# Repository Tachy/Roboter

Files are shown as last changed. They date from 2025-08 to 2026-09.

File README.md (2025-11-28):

Ein rein solarbetriebener Roboter, der auf Pflasterflächen aus den Ritzen wachsendes Unkraut mit KI-Bildauswertung erkennt, anfährt und gezielt mit einer rotierenden Drahtbürste wegbürstet ;)

Mechanik: vorwiegend goBilda-Teile und Pololu-Motoren

Solarpanel: 12 V 50 Wp

Batterie: LiFePo 12 V 6 Ah

Solar-Laderegler: Victron MPPT 75/10

Gehäuseteile: 3D Druck 

Konstruktion Mechanik: Autodesk Fusion 360 private

Entwurf Elektronik: Fritzing

Energiemanagement: Arduino Pro Mini 5V

Motorsteuerung: Arduino MEGA

Bilderkennung mit KI: Raspberry Pi 4B mit RaspBerry HQ Kamera

Besonderheit: wurde zur Einarbeitung in KI vollständig "vibe" coded, über den github-Copilot mit Agent / Auto

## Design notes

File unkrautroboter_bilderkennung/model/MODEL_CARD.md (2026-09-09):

# Model Card – Unkrautroboter Detektionsmodell

Provenienz-Datei für das auf dem Pi laufende YOLO-Modell. Das eigentliche Gewicht
(`best.pt`, `best_ncnn_model/`, `best.onnx`) ist **nicht** in Git – es lebt auf der
Trainingsmaschine `.17` unter `~/lightly/models/registry/<ts>/` und kommt per
`bin/deploy-model.sh` auf den Pi. Diese Datei wird vom Trainer (`yolo-training/trainer/
train_now.py`) geschrieben und bei einer Promotion vom Menschen committet.

## Aktuell ausgeliefert

| Feld | Wert |
|---|---|
| Registry-ID | `20260909213903` (`.17:~/lightly/models/registry/20260909213903/`) |
| Dateien | `best.pt`, `best_ncnn_model/`, `best.onnx` |
| best.pt sha256 | `2101b0efd090f16339e3cd45afe058cd4d989780ad05c420fc0ecb69ca061c5d` |
| Architektur | **YOLO26s** |
| Laufzeit auf dem Pi | NCNN FP16 (`YOLO_RUNTIME="ncnn"`) |
| Klassen | `0: unkraut`, `1: moos` |
| Trainings-/Inferenz-imgsz | 1280 |
| Basisgewichte | `yolo26s.pt` |
| ultralytics | 8.4.146 |
| Holdout-mAP50-95 | 0.955 — **auf Fake-Bildern, nicht aussagekräftig** |
| Gate | bypassed (`--no-gate`, Bootstrap) |
| Datum | 2026-09-09 |
| Quelle | `train_now.py --base yolo26s.pt` auf ~44 **synthetischen** Bildern |

> ⚠️ **Bootstrap-Modell.** Nur der Architektur-/Pipeline-Umstieg v8m → YOLO26s NCNN@1280.
> Auf Fake-Bildern trainiert, erkennt kein echtes Unkraut. Wird beim ersten Echtdaten-Lauf
> über die Modell-OTA ersetzt (Dashboard-Button, Checkbox „Basis: YOLO26s" dann NICHT mehr
> nötig). v8m-Fallback liegt auf dem Pi unter `model/best.pt.v8m`.

## Historie

- 2026-09-09 – **YOLO26s**, imgsz 1280, NCNN FP16, Klassen `unkraut`/`moos`. Bootstrap
  auf synthetischen Bildern, um Trainings-Pipeline + Pi-Laufzeit auf YOLO26 umzustellen.
  Registry `20260909213903` auf `.17`, manuell in `/home/admin/model/` gestaged +
  `config.py` auf `ncnn`/1280 geflippt.
- 2025-08-13 – YOLOv8m, imgsz 640, sha256 `c2c24c64…f61a244`, Basis `yolov8m.pt`. Erster
  in Git eingecheckter Stand; ab Plan *adaptive-orbiting-fountain* aus Git entfernt
  (`git rm --cached`) und auf `.17` als „home of record" abgelegt. Liegt auf dem Pi noch
  als `model/best.pt.v8m` (Notfall-Rückfall).

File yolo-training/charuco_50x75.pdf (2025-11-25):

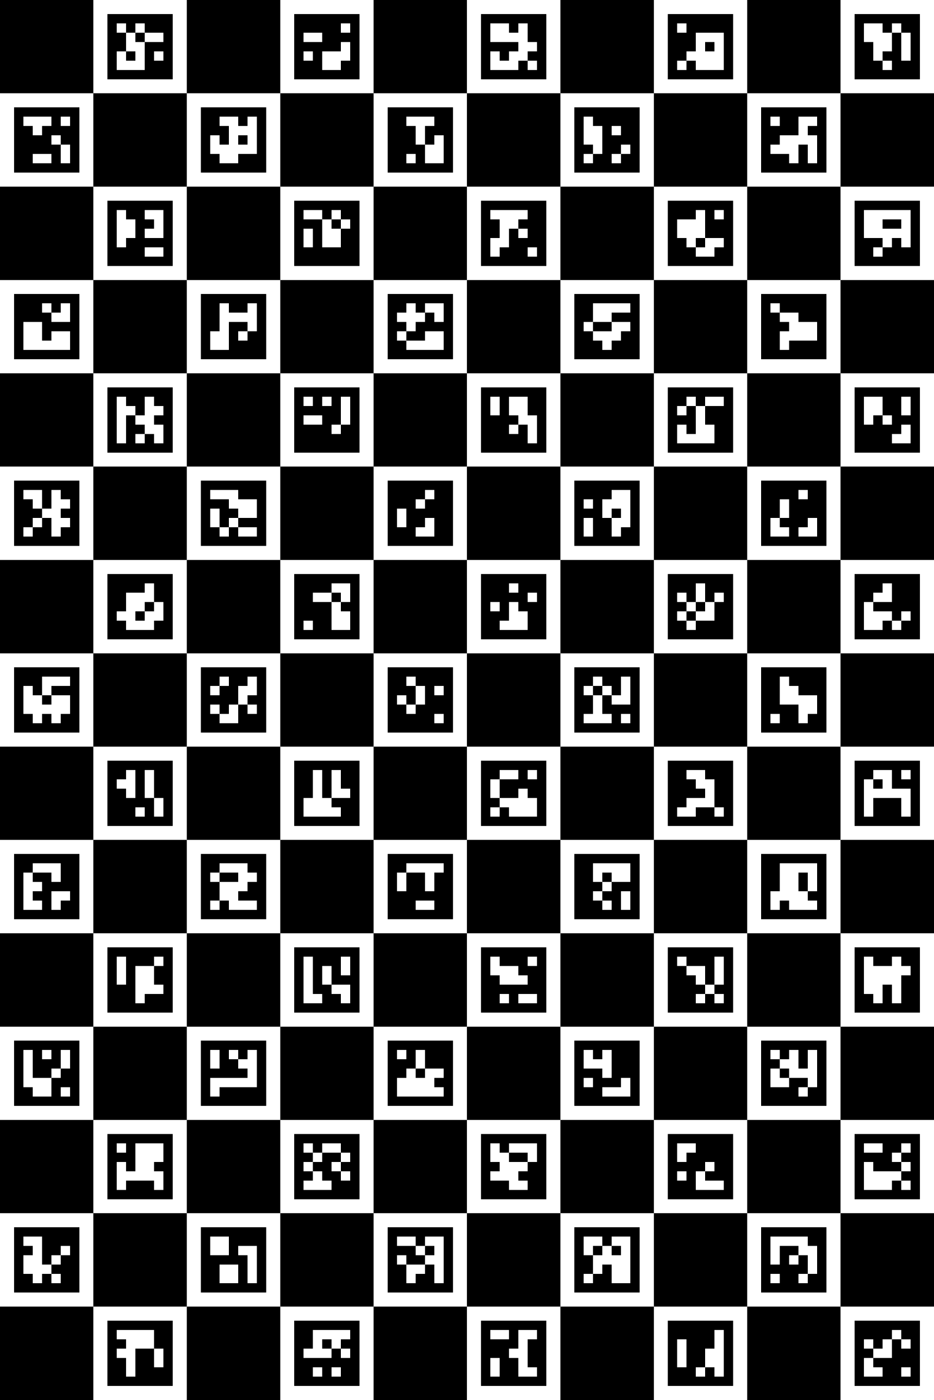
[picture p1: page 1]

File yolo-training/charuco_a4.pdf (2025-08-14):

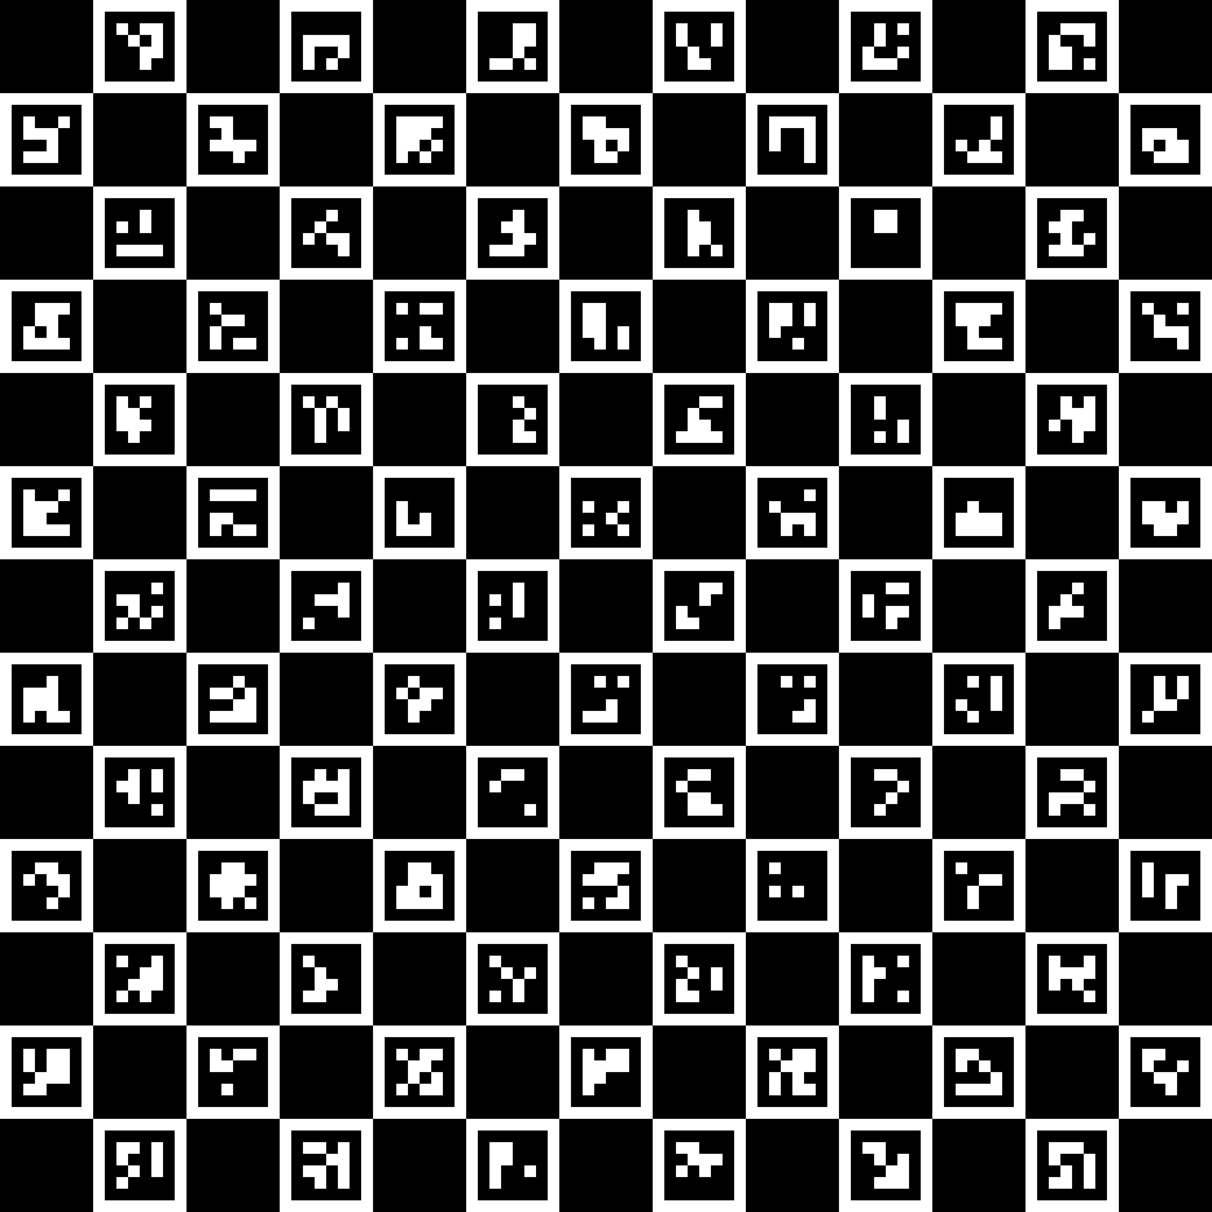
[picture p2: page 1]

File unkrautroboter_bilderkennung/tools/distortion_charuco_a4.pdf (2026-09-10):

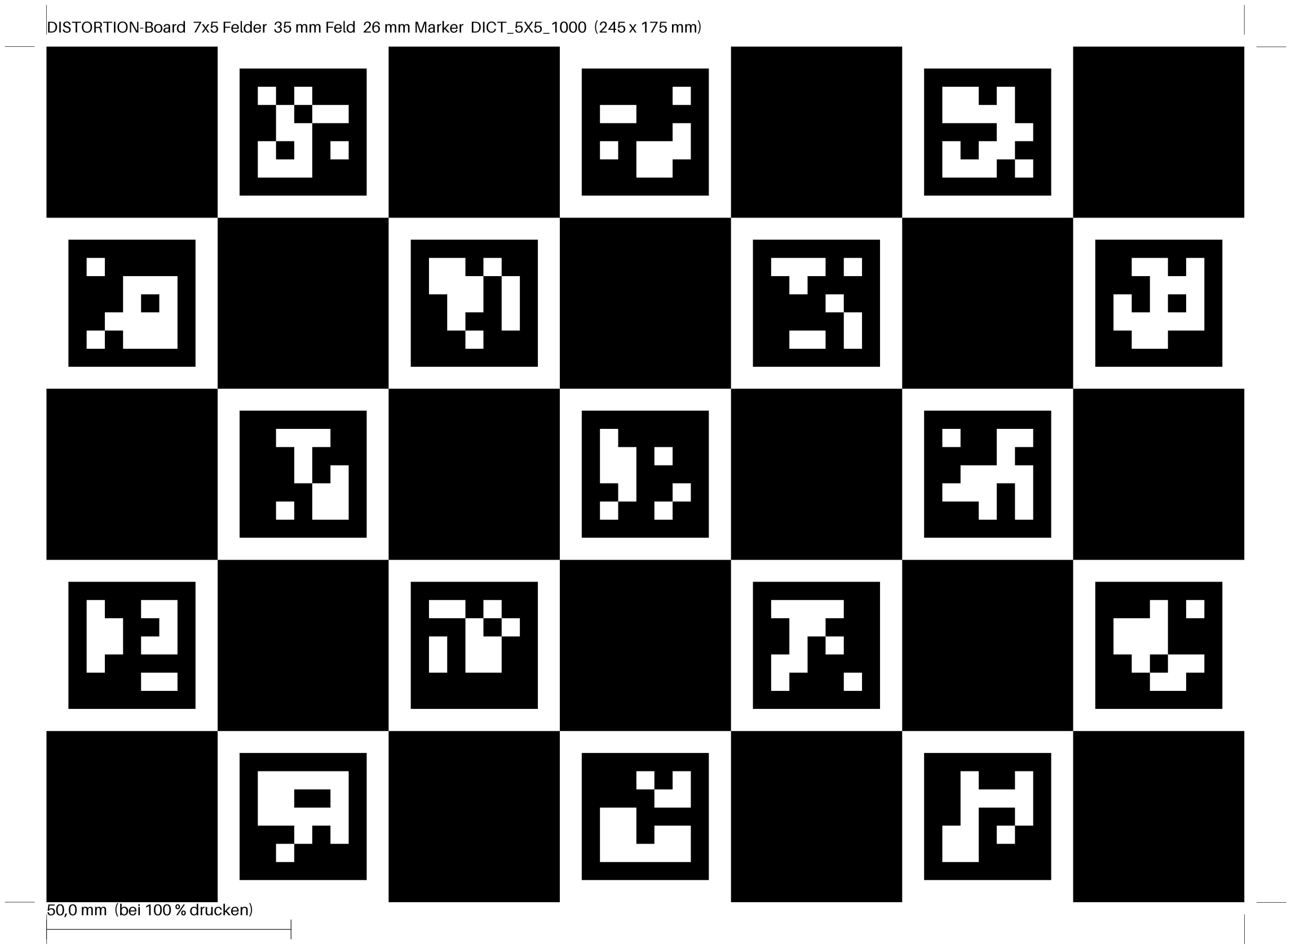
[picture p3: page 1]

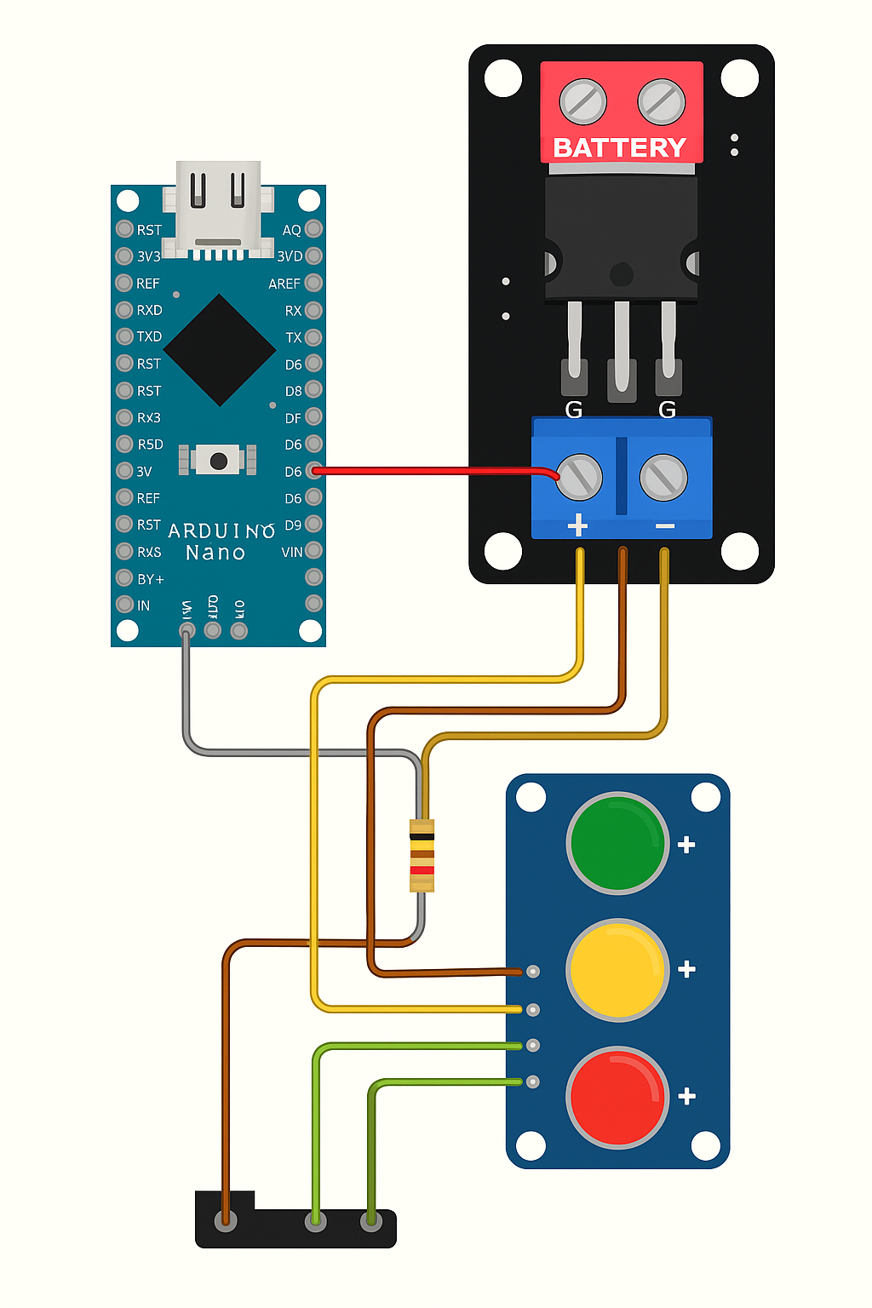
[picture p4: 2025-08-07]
Schaltplan mit Arduino und MOSFET.png

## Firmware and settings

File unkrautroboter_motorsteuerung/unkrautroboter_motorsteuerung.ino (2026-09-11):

#include <ArduinoJson.h>
#include <LowPower.h>
#include <U8g2lib.h>
#include <Wire.h>
#include <avr/wdt.h>

// --- Hardware-Watchdog (M7) ---
// Auf 0 setzen, falls der WDT am Prüfstand Probleme macht (z. B. Resets mitten im
// AUTO-Zyklus). Die frühe Abschaltung in .init3 bleibt in jedem Fall aktiv und
// verhindert eine Reset-Schleife mit dem MEGA-Bootloader.
#define ENABLE_WATCHDOG 1
#if ENABLE_WATCHDOG
#define WDT_FEED() wdt_reset()
#define WDT_ARM() wdt_enable(WDTO_8S)
#else
#define WDT_FEED() ((void)0)
#define WDT_ARM() ((void)0)
#endif

// Läuft in .init3 (vor main()/setup()): WDT bei JEDEM Reset sofort abschalten,
// sonst kann ein WDT-Reset mit dem Standard-Bootloader in einer Schleife hängen.
void wdtInitEarly(void) __attribute__((naked)) __attribute__((used)) __attribute__((section(".init3")));
void wdtInitEarly(void) {
    MCUSR = 0;
    wdt_disable();
}

// INA260 I2C address (default)
#define INA260_ADDR 0x40

// Flag whether INA260 is present on the I2C bus
static bool ina260_present = false;

// OLED configuration (AZ-Delivery 1.3" 128x64 I2C)
#define SCREEN_WIDTH 128
#define SCREEN_HEIGHT 64
// U8g2 SH1106 driver (we only support SH1106 now)
U8G2_SH1106_128X64_NONAME_F_HW_I2C u8g2_sh(U8G2_R0, /* reset=*/U8X8_PIN_NONE);

// Simple 21x8 text buffer (6x8 font => 21 cols x 8 rows)
static char oled_lines[8][22]; // 21 chars + NUL
static uint8_t oled_line_count = 0;
static char oled_cur[22];
static uint8_t oled_cur_len = 0;
// Flag whether the last oled_cur is already present in oled_lines (so debug() overwrites)
static bool oled_has_current_line = false;
// Flag whether OLED init succeeded
static bool oled_present = false;

// === Globale Variablen für robusten Serial-Empfang ===
#define SERIAL_BUFFER_SIZE 256
static volatile char serialRxBuffer[SERIAL_BUFFER_SIZE];
static volatile uint16_t serialRxHead = 0;
static volatile bool serialLineReady = false;

// === KONSTANTEN ===
#define PWM_MIN 60
#define PWM_MIN_RAD 40
#define MAX_KOORDINATEN 50
#define PWM_MAX 255
#define RAMP_UP_TIME_MS 1000
#define RAMP_DOWN_TIME_MS 1000

// --- Bewegungs-Sicherheit (C1): jede blockierende Bewegung bricht ab, wenn sie
//     zu lange dauert oder die Encoder keinen Fortschritt mehr melden. ---
// Werte großzügig; am Prüfstand feinjustieren. MOVE_TIMEOUT_MS ist die harte
// Obergrenze, STALL_* nur die schnellere Reaktion bei echtem Stillstand.
#define MOVE_TIMEOUT_MS 50000UL  // Gesamt-Timeout je Bewegung (setzeX/Z, fahreStrecke)
#define CALIB_TIMEOUT_MS 50000UL // Timeout je Referenzfahrt in setup()
#define STALL_TIMEOUT_MS 3000UL  // kein Encoder-Fortschritt -> Abbruch
#define STALL_MIN_DELTA 3        // Impulse, die als "Fortschritt" zählen

// --- Ausbleibende Pi-Antwort (H1b): nach so vielen erfolglosen GETXY-Zyklen
//     geht der Arduino zurück in den sicheren Wartezustand, statt blind zu fahren. ---
#define MAX_NO_REPLY 3

// Fehler-/Statusflags
volatile bool moveFault = false;    // letzte Bewegung per Timeout/Stall abgebrochen
bool calibOk = false;               // Referenzfahrten X und Z erfolgreich (Endschalter)
bool calibFaultFromPi = false;      // Pi hat NOCALIB gemeldet (keine Welttransformation)
uint8_t noReplyCount = 0;           // aufeinanderfolgende GETXY ohne Pi-Antwort
volatile bool abortRequested = false; // MODE:MANUAL während AUTO -> Zyklus abbrechen (M4)

#define RAD_DURCHMESSER_MM 96.0
#define ENCODER_IMPULSE_UMD 4800
#define RAD_UMFANG_MM (PI * RAD_DURCHMESSER_MM)
#define IMPULSE_PRO_MM (ENCODER_IMPULSE_UMD / RAD_UMFANG_MM)

// Betriebsmodus
enum Mode {
    WAITING_FOR_START, // Initialer Zustand
    MANUAL,
    AUTO,
    EXTRINSIK // Kamera-Extrinsik-Kalibrierung: Pi steuert X per GOTOX:<mm>
};

Mode currentMode = WAITING_FOR_START; // Startet im Wartezustand

// Rad links
#define RPWM_L 5
#define LPWM_L 6

#define ENC_L_A 2 // Interrupt
#define ENC_L_B 22

// Rad rechts
#define RPWM_R 7
#define LPWM_R 8

#define ENC_R_A 3 // Interrupt
#define ENC_R_B 23

// Arduino-Pins Schlitten-Motor X-Achse (Mikro-Motor)
#define RPWM_X 44
#define LPWM_X 45

#define ENC_X_A 18 // Interrupt
#define ENC_X_B 24

#define END_X_L 27
#define END_X_R 28

// Arduino-Pins Schlitten-Motor Z-Achse (Mikro-Motor)
#define RPWM_Z 11
#define LPWM_Z 12

#define ENC_Z_A 19 // Interrupt
#define ENC_Z_B 25

#define END_Z_O 29
#define END_Z_U 30

#define RESET_PRO_MINI 32
#define RELAIS_HS 33

// Arduino-Pins Bürstenmotor
#define PWM_BRUSH 46

// Enable-Pin für alle Brücken
#define EN_BRIDGE 47

// Brush encoder (A/B)
#define ENCODER_BRUSH_A 26 // Polling (kein Interrupt)

// Endschalter: true = NC (Normally Closed) wiring (pressed == HIGH),
// false = NO (Normally Open) wiring (pressed == LOW)
#define END_SWITCH_NC true

// Pins für Serial 0 sind fest: 0 (RX), 1 (TX)

// Bürstenmotor
#define BRUSH_CPR 106
#define BRUSH_TARGET_RPM 2200

#define ENCODER_X_CPR 600
#define ENCODER_Z_CPR 600
#define SCHRAUBEN_STEIGUNG_MM 8.0
#define IMPULSE_X_PRO_MM (ENCODER_X_CPR / SCHRAUBEN_STEIGUNG_MM)
#define IMPULSE_Z_PRO_MM (ENCODER_Z_CPR / SCHRAUBEN_STEIGUNG_MM)

#define RAMP_X_IMPULSE 2000 // Impulse bis zur Rampe
#define RAMP_Z_IMPULSE 2000
#define RAMP_RAD_IMPULSE 10000
#define MIN_RAMP_IMP 0

#define MAX_X 440
#define MAX_Z 58
#define MITTEX 300 // Kamera-/Aufnahmeposition (AUTO-GETXY und EXTRINSIK)

volatile long encoderLinks = 0;
volatile long encoderRechts = 0;
volatile long encoderX = 0;
volatile long encoderZ = 0;
volatile long deltaEncoderRad = 0;

// Maximale Länge für einen Befehl über die serielle Schnittstelle
#define MAX_CMD_LENGTH 50

// MAX_KOORDINATEN ist oben im KONSTANTEN-Block definiert.
struct Zielpunkt {
    float x_mm;
    float y_mm;
};

Zielpunkt ziele[MAX_KOORDINATEN];
int zielCount = 0;
float aktuelleY_mm = 0;

// Flags für Koordinatenempfang in processSerialCommand()
static bool waitingForCoordinates = false;
static bool coordinatesComplete = false;

volatile long encoderBrush = 0;

// --- 18 kHz PWM-Initialisierung für alle 16-Bit-Timer (1,3,4,5) inkl. Bürste ---
const uint16_t MOTOR_PWM_TOP = 110; // ~18 kHz bei 16 MHz, N=1

// Helper: returns true when the end switch is currently pressed (according to wiring)
static inline bool endPressed(uint8_t pin) {
    if (END_SWITCH_NC)
        return (digitalRead(pin) == HIGH);
    else
        return (digitalRead(pin) == LOW);
}

// Build and send the persistent 8-line buffer to the display.
// This function uses the global `oled_cur` contents. If `oled_has_current_line`
// is true the current contents overwrite the last displayed line, otherwise
// the contents are appended as a new line (with scrolling when full).
void oledPush() {
    if (!oled_present)
        return;

    // Make a local copy of the current line (may be empty)
    char tmp[22];
    if (oled_cur_len > 21)
        oled_cur_len = 21;
    memcpy(tmp, oled_cur, oled_cur_len);
    tmp[oled_cur_len] = '\0';

    if (oled_has_current_line) {
        // overwrite last displayed line
        strncpy(oled_lines[oled_line_count - 1], tmp, 22);
        oled_lines[oled_line_count - 1][21] = '\0';
    } else {
        // append as new line (scroll if needed)
        if (oled_line_count < 8) {
            strncpy(oled_lines[oled_line_count++], tmp, 22);
            oled_lines[oled_line_count - 1][21] = '\0';
        } else {
            for (int i = 0; i < 7; i++)
                strncpy(oled_lines[i], oled_lines[i + 1], 22);
            strncpy(oled_lines[7], tmp, 22);
            oled_lines[7][21] = '\0';
        }
        oled_has_current_line = true;
    }

    // redraw using u8g2_sh only
    const uint8_t row_h = 7;
    u8g2_sh.clearBuffer();
    u8g2_sh.setFont(u8g2_font_5x7_tr);
    for (uint8_t i = 0; i < oled_line_count; i++) {
        uint8_t y = (i + 1) * row_h; // baseline offset for u8g2
        if (y >= SCREEN_HEIGHT)
            break;
        u8g2_sh.drawStr(0, y, oled_lines[i]);
    }
    u8g2_sh.sendBuffer();
    // small pause to give the display time to update physically
    delay(5);
}
// Append text to current line (no newline)
void debug(const char *s) {
    if (!oled_present) {
        // no OLED -> nothing to do
        return;
    }
    if (!s)
        return;
    while (*s) {
        if (oled_cur_len >= 21)
            break;
        oled_cur[oled_cur_len++] = *s++;
    }
    oled_cur[oled_cur_len] = '\0';
    // After every append, update the persistent buffer and redraw
    oledPush();
}
void debugln(const char *s) {
    if (!oled_present) {
        // no OLED -> nothing to do
        return;
    }
    if (s && *s)
        debug(s);
    // Ensure the current line has been pushed, then advance to a fresh line
    // (debug already called oledPush()). Clear current buffer so next debug
    // will create a new line.
    oled_cur_len = 0;
    oled_cur[0] = '\0';
    oled_has_current_line = false;
}

// Move cursor one line up so the next debug/debugln overwrites the previous line.
// Implementation: copy last displayed line into the current-line buffer and remove
// it from the displayed lines, then redraw. The next debug()/debugln() will
// append/replace that line.
void debugCursorUp() {
    if (!oled_present) {
        // no OLED -> nothing to do
        return;
    }

    if (oled_line_count == 0) {
        // nothing to move up to -> clear current buffer only
        oled_cur_len = 0;
        oled_cur[0] = '\0';
        return;
    }

    // copy last displayed line into current buffer (no visual change)
    strncpy(oled_cur, oled_lines[oled_line_count - 1], 21);
    oled_cur[21] = '\0';
    oled_cur_len = strlen(oled_cur);

    // remove last line from buffer so next debug/debugln will overwrite that row
    oled_line_count--;
}

// Hilfsfunktion: leert Hardware-RX-Buffer in Software-Buffer
// Wird von Timer2-ISR alle 5ms UND vom Framework nach loop() aufgerufen
void serialEvent() {
    while (Serial.available() && !serialLineReady) {
        char c = Serial.read();

        if (c == '\n') {
            serialRxBuffer[serialRxHead] = '\0';
            serialLineReady = true;
            return;
        } else if (c != '\r') {
            if (serialRxHead < SERIAL_BUFFER_SIZE - 1) {
                serialRxBuffer[serialRxHead++] = c;
            } else {
                // Buffer voll -> Reset (verhindert Überlauf)
                serialRxHead = 0;
            }
        }
    }
}

// Timer2 Compare Match ISR: ruft serialEvent() alle 5ms im Hintergrund auf
// Läuft parallel zu Encoder-ISRs und Bewegungsfunktionen
ISR(TIMER2_COMPA_vect) {
    serialEvent(); // Hardware-RX-Buffer in Software-Buffer kopieren
}

void setupTimer2SerialPolling() {
    // Timer2: 8-Bit, Prescaler 1024 -> 16 MHz / 1024 / 78 = ~200 Hz (5 ms)
    // Bei 115200 Baud: 11.5 Zeichen/ms -> 5ms = max 57 Zeichen -> Hardware-Buffer (64 Byte) sicher
    cli(); // Interrupts global aus

    TCCR2A = 0;
    TCCR2B = 0;
    TCNT2 = 0;
    OCR2A = 77;                                        // (16000000 / 1024 / 200) - 1 = 77.125
    TCCR2A |= (1 << WGM21);                            // CTC mode
    TCCR2B |= (1 << CS22) | (1 << CS21) | (1 << CS20); // Prescaler 1024
    TIMSK2 |= (1 << OCIE2A);                           // Enable Compare Match Interrupt

    sei(); // Interrupts global an
}

// Neue nicht-blockierende readSerialLine() (aufgerufen in loop/processSerialCommand)
bool readSerialLine(String &buffer) {
    if (serialLineReady) {
        buffer = String((const char *)serialRxBuffer);
        serialRxHead = 0;
        serialLineReady = false;
        return true;
    }
    return false;
}

// Motoren
void motorAnalogWrite(uint8_t pin, uint8_t pwm) {
    // PWM schreiben (0..255 auf 0..TOP abbilden)
    uint16_t val = (uint32_t)pwm * MOTOR_PWM_TOP / 255u;
    switch (pin) {
    case RPWM_L:
        OCR3A = val;
        break; // Timer3, OC3A, Rad links
    case LPWM_L:
        OCR4A = val;
        break; // Timer4, OC4A, Rad links
    case LPWM_R:
        OCR4B = val;
        break; // Timer4, OC4B, Rad rechts
    case RPWM_R:
        OCR4C = val;
        break; // Timer4, OC4C
    case RPWM_Z:
        OCR1A = val;
        break; // Timer1, OC1A, Z-Achse
    case LPWM_Z:
        OCR1B = val;
        break; // Timer1, OC1B, Z-Achse
    case RPWM_X:
        OCR5C = val;
        break; // Timer5, OC5C, X-Achse
    case LPWM_X:
        OCR5B = val;
        break; // Timer5, OC5B, X-Achse
    case PWM_BRUSH:
        OCR5A = val;
        break; // Timer5, OC5A, Bürste
    default:
        return; // Unbekannter Pin
    }
}
void initMotorPWM18kHz() {
    // Timer1: Pins 11 (OC1A), 12 (OC1B)
    TCCR1A = 0;
    TCCR1B = 0;
    TCNT1 = 0;
    ICR1 = MOTOR_PWM_TOP;
    TCCR1A = (1 << WGM11) | (1 << COM1A1) | (1 << COM1A0) // OC1A invertiert
             | (1 << COM1B1) | (1 << COM1B0);             // OC1B invertiert
    TCCR1B = (1 << WGM13) | (1 << WGM12) | (1 << CS11);   // Prescaler 8
    OCR1A = 0;
    OCR1B = 0;

    // Timer3: Pin 5 (OC3A)
    TCCR3A = 0;
    TCCR3B = 0;
    TCNT3 = 0;
    ICR3 = MOTOR_PWM_TOP;
    TCCR3A = (1 << WGM31) | (1 << COM3A1) | (1 << COM3A0); // OC3A invertiert (Pin 5)
    TCCR3B = (1 << WGM33) | (1 << WGM32) | (1 << CS31);    // Prescaler 8
    OCR3A = 0;

    // Timer4: Pins 6 (OC4A), 7 (OC4B), 8 (OC4C)
    TCCR4A = 0;
    TCCR4B = 0;
    TCNT4 = 0;
    ICR4 = MOTOR_PWM_TOP;
    TCCR4A = (1 << WGM41) | (1 << COM4A1) | (1 << COM4A0) // OC4A invertiert (Pin 6)
             | (1 << COM4B1) | (1 << COM4B0)              // OC4B invertiert (Pin 7)
             | (1 << COM4C1) | (1 << COM4C0);             // OC4C invertiert (Pin 8)
    TCCR4B = (1 << WGM43) | (1 << WGM42) | (1 << CS41);   // Prescaler 8
    OCR4A = 0;
    OCR4B = 0;
    OCR4C = 0;

    // Timer5: Pins 44 (OC5C), 45 (OC5B), 46 (OC5A)
    TCCR5A = 0;
    TCCR5B = 0;
    TCNT5 = 0;
    ICR5 = MOTOR_PWM_TOP;
    TCCR5A = (1 << WGM51) | (1 << COM5A1) | (1 << COM5A0) // OC5A invertiert (Pin 46)
             | (1 << COM5B1) | (1 << COM5B0)              // OC5B invertiert (Pin 45)
             | (1 << COM5C1) | (1 << COM5C0);             // OC5C invertiert (Pin 44)
    TCCR5B = (1 << WGM53) | (1 << WGM52) | (1 << CS51);   // Prescaler 8
    OCR5A = 0;
    OCR5B = 0;
    OCR5C = 0;

    pinMode(RPWM_L, OUTPUT);
    pinMode(LPWM_L, OUTPUT);
    pinMode(RPWM_R, OUTPUT);
    pinMode(LPWM_R, OUTPUT);
    pinMode(RPWM_X, OUTPUT);
    pinMode(LPWM_X, OUTPUT);
    pinMode(RPWM_Z, OUTPUT);
    pinMode(LPWM_Z, OUTPUT);
    pinMode(PWM_BRUSH, OUTPUT);

    // Ensure motors start in stopped state using the same inverted mapping
    motorAnalogWrite(RPWM_L, 0);
    motorAnalogWrite(LPWM_L, 0);
    motorAnalogWrite(RPWM_R, 0);
    motorAnalogWrite(LPWM_R, 0);
    motorAnalogWrite(RPWM_X, 0);
    motorAnalogWrite(LPWM_X, 0);
    motorAnalogWrite(RPWM_Z, 0);
    motorAnalogWrite(LPWM_Z, 0);
    motorAnalogWrite(PWM_BRUSH, 0);

    attachInterrupt(digitalPinToInterrupt(ENC_L_A), isrEncoderLinks, CHANGE);
    attachInterrupt(digitalPinToInterrupt(ENC_R_A), isrEncoderRechts, CHANGE);
    attachInterrupt(digitalPinToInterrupt(ENC_X_A), isrEncoderX, CHANGE);
    attachInterrupt(digitalPinToInterrupt(ENC_Z_A), isrEncoderZ, CHANGE);

    // Enable all bridges (if needed, otherwise remove this line)
    pinMode(EN_BRIDGE, OUTPUT);
    digitalWrite(EN_BRIDGE, HIGH);
}

// Note: brush encoder is sampled when needed inside getBrushRPM().
void isrEncoderLinks() {
    if (digitalRead(ENC_L_A) == digitalRead(ENC_L_B))
        encoderLinks++;
    else
        encoderLinks--;
}
void isrEncoderRechts() {
    if (digitalRead(ENC_R_A) == digitalRead(ENC_R_B))
        encoderRechts--;
    else
        encoderRechts++;
}
void isrEncoderX() {
    if (digitalRead(ENC_X_A) == digitalRead(ENC_X_B))
        encoderX++;
    else
        encoderX--;
}
void isrEncoderZ() {
    if (digitalRead(ENC_Z_A) == digitalRead(ENC_Z_B))
        encoderZ--;
    else
        encoderZ++;
}
void isrEncoderBrush() {
    encoderBrush++;
}

bool kalibriereX() {
    debug("Kalibriere X...");
    unsigned long tStart = millis();
    long stallEnc = encoderX;
    unsigned long stallMs = millis();
    bool ok = true;
    // run until the left end switch is pressed
    while (!endPressed(END_X_L)) {
        WDT_FEED();
        motorAnalogWrite(RPWM_X, 150);
        motorAnalogWrite(LPWM_X, 0);
        delay(5);
        if (millis() - tStart > CALIB_TIMEOUT_MS) {
            ok = false;
            break;
        }
        if (labs(encoderX - stallEnc) >= STALL_MIN_DELTA) {
            stallEnc = encoderX;
            stallMs = millis();
        } else if (millis() - stallMs > STALL_TIMEOUT_MS) {
            ok = false;
            break;
        }
    }
    motorAnalogWrite(RPWM_X, 0);
    motorAnalogWrite(LPWM_X, 0);
    delay(500);
    if (ok) {
        encoderX = 0;
        debugln("OK.");
    } else {
        moveFault = true;
        debugln("X: KALIB-FEHLER");
    }
    return ok;
}
bool kalibriereZ() {
    debug("Kalibriere Z...");
    unsigned long tStart = millis();
    long stallEnc = encoderZ;
    unsigned long stallMs = millis();
    bool ok = true;
    // run until the top end switch is pressed
    while (!endPressed(END_Z_O)) {
        WDT_FEED();
        motorAnalogWrite(RPWM_Z, 150);
        motorAnalogWrite(LPWM_Z, 0);
        delay(5);
        if (millis() - tStart > CALIB_TIMEOUT_MS) {
            ok = false;
            break;
        }
        if (labs(encoderZ - stallEnc) >= STALL_MIN_DELTA) {
            stallEnc = encoderZ;
            stallMs = millis();
        } else if (millis() - stallMs > STALL_TIMEOUT_MS) {
            ok = false;
            break;
        }
    }
    motorAnalogWrite(RPWM_Z, 0);
    motorAnalogWrite(LPWM_Z, 0);
    delay(500);
    if (ok) {
        encoderZ = 0;
        debugln("OK.");
    } else {
        moveFault = true;
        debugln("Z: KALIB-FEHLER");
    }
    return ok;
}
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
void loop() {
    WDT_FEED(); // Watchdog füttern (M7)
    processSerialCommand(); // Prüfe auf neue Kommandos

    sendeStatus();

    // Sofortige Endschalter-Überprüfung im MANUAL-/EXTRINSIK-Modus, damit
    // Endschalter auch dann direkt reagieren, wenn Kommandos selten eintreffen.
    // Reagiert mit der Loop-Frequenz (~10 ms).
    if (currentMode == MANUAL || currentMode == EXTRINSIK) {
        // X-Achse Endschalter (NC wiring: pressed == HIGH)
        if (endPressed(END_X_L) || endPressed(END_X_R)) {
            motorAnalogWrite(RPWM_X, 0);
            motorAnalogWrite(LPWM_X, 0);
        }
        // Z-Achse Endschalter
        if (endPressed(END_Z_O) || endPressed(END_Z_U)) {
            motorAnalogWrite(RPWM_Z, 0);
            motorAnalogWrite(LPWM_Z, 0);
        }
    }

    if (currentMode == WAITING_FOR_START) {
        // Im Wartezustand blinken wir eine LED oder geben periodisch eine Nachricht aus
        static unsigned long lastBlink = 0;
        if (millis() - lastBlink > 1000) { // Jede Sekunde
            debugln("Warte auf Pi4...");
            Serial.println("WAITING");
            lastBlink = millis();
        }
    } else if (currentMode == AUTO) {
        if (calibOk) {
            // Im Auto-Modus kontinuierlich anfragen und abarbeiten
            anfrageUndAbarbeiten();
        } else {
            // Ohne gültige Referenzfahrt kein AUTO-Betrieb.
            static unsigned long lastCalibWarn = 0;
            if (millis() - lastCalibWarn > 2000) {
                debugln("AUTO gesperrt: keine Referenzfahrt");
                Serial.println("FAULT:NOCALIB");
                lastCalibWarn = millis();
            }
        }
    }

    // Kleine Pause um CPU-Last zu reduzieren
    delay(10);
}

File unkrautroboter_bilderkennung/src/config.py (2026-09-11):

# Logging Setup
import logging

LOGLEVEL = (
    logging.INFO
)  # z.B. logging.DEBUG, logging.INFO, logging.WARNING, logging.ERROR
"""
Konfigurationsmodul für den Unkrautroboter.
Enthält alle wichtigen Konstanten und Einstellungen.
"""

# Serial Setup
SIMULATED_SERIAL_PORT = "/tmp/ttyV8"  # Virtueller Port für die Simulation
SERIAL_PORT = "/dev/serial0"  # Echter serieller Port
BAUDRATE = 115200  # Baudrate der seriellen Verbindung

# UDP Setup
UDP_IP = "0.0.0.0"  # Hört auf alle Schnittstellen
UDP_CONTROL_PORT = 5005  # Port für Modusumschaltung
UDP_JOYSTICK_PORT = 5006  # Port für Joystick-Kommandos
UDP_HEARTBEAT_PORT = 5007  # Port für Heartbeat-Messages
# UDP_STATUS_BROADCAST_PORT wurde entfernt (nicht verwendet)
HEARTBEAT_TIMEOUT = 5.0  # Sekunden, wie lange der Stream nach letztem Heartbeat läuft

# Optionale Whitelist für UDP-Steuerung/Joystick (Absender-IP-Adressen oder CIDR-Netze)
# Beispiel: ALLOWED_UDP_SOURCES = ["192.168.179.10", "192.168.179.0/24"]
# Leer lassen, um alle Quellen zu erlauben.
ALLOWED_UDP_SOURCES = ["192.168.179.17", "192.168.179.186", "192.168.179.4"]

# HTTP Server Setup
HTTP_PORT = 8080

# YOLO Setup
USE_DUMMY = False  # Auf False setzen, wenn das echte YOLO-Modell verwendet wird
YOLO_MODEL_PATH = "./model/best.pt"  # z. B. "best.pt"

# Inferenz-Parameter (Subprozess mit Timeout)
YOLO_TIMEOUT_SEC = 40
YOLO_IMG_SIZE = 1280  # Netzgröße; 720p wird auf 1280x736 letterboxed (YOLO26s NCNN FP16)
YOLO_CONF = 0.25  # Konfidenzschwelle
YOLO_IOU = 0.45  # IoU-Schwelle

# Camera Setup
# EIN Kamera-Modus mit zwei Ausgängen (kein Mode-Switch -> Stream reißt nie ab):
#  - main  = CAPTURE_RESOLUTION: alle Einzelbilder (GETXY, EXTRINSIK, DISTORTION,
#            Training) in voller IMX477-Auflösung 4056x3040.
#  - lores = CAMERA_RESOLUTION:  läuft durchgehend als MJPEG-Stream/Vorschau.
# lores wird von picamera2 aus dem VOLLEN `main`-Bildfeld heruntergerechnet
# (kein eigener Crop). Daher muss CAMERA_RESOLUTION dasselbe Seitenverhältnis
# wie CAPTURE_RESOLUTION haben (4:3), sonst wird das Vorschaubild anamorph
# gestaucht. So decken Stream und Einzelbilder dieselbe Sensor-FOV ab, nur in
# unterschiedlicher Auflösung.
CAPTURE_RESOLUTION = (4056, 3040)
CAMERA_RESOLUTION = (1024, 768)
# EXTRINSIK nutzt die volle `main`-Auflösung (subpixelgenaue Ecken). GETXY wird
# aus `main` auf diese Größe heruntergerechnet (kleine, schnelle PNGs); das
# Polynom skaliert die Pixel über ref_wh automatisch hoch.
STILL_RESOLUTION_EXTRINSIK = CAPTURE_RESOLUTION
STILL_RESOLUTION_GETXY = (2028, 1520)

# Kleines ChArUco-Board NUR für den DISTORTION-Modus (K, D). Passt quer auf A4
# (7x35 = 245 mm x 5x35 = 175 mm) und lässt sich plan aufziehen. Dictionary =
# dasselbe wie das große Boden-Board (calibration.DICT_NAME). Für die Intrinsik
# ist der absolute Maßstab egal – nur das Feld/Marker-Verhältnis zählt.
# Board-Bild erzeugen: python tools/gen_distortion_board.py
DISTORTION_BOARD_SQUARES = (7, 5)       # (x, y)
DISTORTION_BOARD_SQUARE_MM = 35.0
DISTORTION_BOARD_MARKER_MM = 26.0

# Training Setup
TRAINING_IMAGE_DIR = "./training/"

# Firmware upload directory for .hex files (Pi -> Mega flashing)
UPLOAD_DIR = "./upload/"

# --- Modell-OTA: model_<ts>.tar in MODEL_UPLOAD_DIR ablegen, Pi tauscht in MANUAL ---
MODEL_UPLOAD_DIR = "./model_upload/"          # Inbox für Modell-Tars
MODEL_DIR = "./model/"                        # Zielverzeichnis (best.pt, best_ncnn_model/, ...)
YOLO_NCNN_DIR = "./model/best_ncnn_model"     # genutzt bei YOLO_RUNTIME == "ncnn"
YOLO_RUNTIME = "ncnn"                         # "pt" | "ncnn" | "onnx"
YOLO_EXPECTED_CLASSES = ["unkraut", "moos"]   # Reihenfolge maßgeblich; OTA weist bei Abweichung ab
# Läuft auf YOLO26s NCNN FP16 @ imgsz 1280 (Pi 4B ~5-8 s, ultralytics 8.4.146).
# Das aktuelle Modell ist ein Bootstrap auf Fake-Bildern (nur Architektur-/Pipeline-
# Umstieg) – wird beim ersten Echtdaten-Lauf über die Modell-OTA ersetzt.
# Zurück auf v8m im Notfall: YOLO_RUNTIME="pt", YOLO_IMG_SIZE=640,
# cp model/best.pt.v8m model/best.pt.

# GPIO-Pin (BCM) an der Raspberry Pi, der mit dem RESET-Pin des Mega verbunden ist.
# Wenn None, wird kein Reset per GPIO durchgeführt. Hinweis: RESET ist aktiv LOW.
FW_RESET_GPIO = 23  # z.B. 23
# Firmware reset tuning (seconds)
# Duration die RESET-Leitung kurz aktivieren (Sekunden)
FW_RESET_PULSE_SEC = 0.1
# Verzögerung nach dem Loslassen der RESET-Leitung bevor avrdude startet (Sekunden)
FW_RESET_POST_PULSE_WAIT = 0.1

# Weltkoordinaten: optionaler XY-Versatz (mm), um den Ursprung zu verschieben (z. B. unter die linke Bürste)
# Beispiel: WORLD_OFFSET_XY_MM = (x_mm, y_mm) – wird von pixel_to_world subtrahiert
WORLD_OFFSET_XY_MM = (0.0, 0.0)

# EXTRINSIK: Grad des Pixel->mm-Polynoms ("Kurvenmatrix"), das die Extrinsik aus
# Pose + K/D backt und als ground_poly.npz speichert. 3 reicht für normale
# Objektive; finalize hebt bei zu großem Fit-Residuum selbst auf 4 an.
EXTRINSIK_POLY_DEGREE = 3
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

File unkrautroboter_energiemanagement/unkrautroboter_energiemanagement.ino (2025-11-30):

/*
  Energiewächter – Arduino Pro Mini (5V)
  --------------------------------------
  • Nur PV- und Batterie-Spannungen über hochohmige Spannungsteiler (keine Strommessung).
  • Entscheidung „Victron + PV trennen/verbinden“ erfolgt AUSSCHLIESSLICH über die PV-Spannung
    mit Hysterese + Zeitfilter.
  • Hauptsystem (XL4015) wird abhängig von LiFePO₄-SoC (per Ruhespannungs-Näherung) geschaltet.
  • 4x bistabile 12V-Relais (je 2 Spulen) über 2x ULN2003:
      R1: PV -> Victron (SET=verbinden, RESET=trennen)
      R2: BAT -> Victron (SET=verbinden, RESET=trennen)
      R3: Precharge -> XL4015 (SET=ein,  RESET=aus)
      R4: Hauptpfad  -> XL4015 (SET=ein,  RESET=aus)

  WICHTIG:
  - Schwellen **auf DEIN System kalibrieren!**
  - ULN2003: COM-Pin an +12 V (Freilaufdioden), gemeinsame Masse zum Arduino.
  - Bistabile Relais nur kurz pulsweise ansteuern (RELAY_PULSE_MS).
  - Pi-Shutdown-Signal beachten (PI_SHDN_PIN), optionales ACK (PI_ACK_PIN).

  Reihenfolgen:
  - Einschalten Victron: zuerst BAT verbinden (R2_SET), dann PV verbinden (R1_SET)
  - Ausschalten Victron: zuerst PV trennen (R1_RST), dann BAT trennen (R2_RST)
  - Hauptsystem EIN: Precharge (R3_SET) → warten → Hauptpfad (R4_SET) → Precharge AUS (R3_RST)
  - Hauptsystem AUS: Hauptpfad AUS (R4_RST) → Precharge AUS (R3_RST)

  HINWEISE ZUR KALIBRIERUNG:
  - PV_DISCONNECT_V / PV_RECONNECT_V: An realer Anlage „einmessen“ (Morgendämmerung/Abend/Wolken).
    Ziel: Keine Schaltspiele, aber zügiges Verbinden bei brauchbarer Sonne.
  - LiFePO₄-Schwellen BAT_SOC10_V / BAT_SOC50_V:
    Bei Last/unter Ladung verschiebt sich die Klemmenspannung → großzügige Hysterese nutzen.
  - PRECHARGE_MS nach Eingangskapazität des XL4015 und R_pre dimensionieren.
  - PI_ACK_PIN: Wenn nicht verdrahtet, optional ignorieren und nur via Timeout abschalten.

  ACHTUNG:
  - Die Spannungswerte sind Richtwerte und müssen an dein System angepasst werden!
  - Die Relais sollten nur kurz angesteuert werden, um sie nicht zu beschädigen.
  - Achte auf die Freilaufdioden der Relais, wenn du ULN2003 oder ähnliche Treiber verwendest.
  - Teste das System gründlich, bevor du es im Dauerbetrieb einsetzt!
*/

#include <Arduino.h> // type: ignore
#include <EEPROM.h>
#include <LowPower.h>

// ========================= Pins (anpassen, falls nötig) =========================
const uint8_t R1_RST = 2; // PV trennen
const uint8_t R1_SET = 3; // PV verbinden
const uint8_t R2_RST = 4; // Batterie trennen
const uint8_t R2_SET = 5; // Batterie verbinden
const uint8_t R3_RST = 6; // Precharge aus
const uint8_t R3_SET = 7; // Precharge ein
const uint8_t R4_RST = 8; // Hauptpfad XL4015 aus
const uint8_t R4_SET = 9; // Hauptpfad XL4015 ein

const uint8_t LED_RED = 12;    // LED rot
const uint8_t LED_YELLOW = 11; // LED gelb
const uint8_t LED_GREEN = 10;  // LED grün

const uint8_t PI_SHDN_PIN = 13; // Ausgang: HIGH → Pi soll Shutdown starten

const uint8_t ADC_BAT = A1;
const uint8_t ADC_PV = A2;
// Optionaler Hardware-Override: Schalter an A0 gegen GND.
// Geschlossen (gegen GND): keine Wirkung. Offen: zwinge MainState = Off (Override).
const uint8_t MAIN_OVERRIDE_PIN = A0;

// ========================= ADC & Teiler (ANPASSEN!) =========================
// Tipp: Bei hochohmigen Teilern je 100 nF direkt am ADC-Pin gegen GND.
// Referenz hier: Vcc = 5.0 V (Standard Pro Mini 5V)
const float ADC_REF_V = 5.0;
const float ADC_MAX = 1023.0;

// U_in = U_adc * ((Rtop + Rbottom) / Rbottom)
// Kalibriert: Messgerät 13.30 V → Regler zeigte 13.37 V
// Korrekturfaktor: 13.30/13.37 ≈ 0.9948 → BAT_RTOP von 104400 auf 103900
const float BAT_RTOP = 104000.0;   // kalibriert bei 13.30 V
const float BAT_RBOTTOM = 10000.0; // z. B. 10k
// Nach Kalibrierung (zwei Messpunkte: 19.07/18.39 und 16.28/15.68)
// Faktor ≈ mean(19.07/18.39, 16.28/15.68) ≈ 1.0379 -> neuer Rtop ≈ 187.2k
const float PV_RTOP = 187200.0;   // angepasst ~187.2k
const float PV_RBOTTOM = 10000.0; // z. B. 10k

// ========================= LiFePO₄-SoC-Schwellen (4S) =========================
// Richtwerte für *Ruhespannung* (Last weg, Temperatur ~20–25°C):
// ~10%: ≈12.9–13.0 V  |  ~50%: ≈13.2 V  |  ~100%: 13.5–13.6 V
// Hysterese großzügig, um Flattern zu vermeiden.
const float BAT_SOC10_V = 12.40;   // ~10% SoC → Hauptsystem herunterfahren
const float BAT_SOC10_HYST = 0.10; // 100 mV

const float BAT_SOC50_V = 13.00;   // ~50% SoC → Hauptsystem einschalten
const float BAT_SOC50_HYST = 0.08; // 80 mV

// ========================= PV-Entscheidung NUR über PV-Spannung =========================
// Reine PV-Heuristik mit Hysterese + Zeitfilter:
// - Wenn PV_V < PV_DISCONNECT für PV_DISCONNECT_HOLD_MS ⇒ Victron trennen
// - Wenn PV_V > PV_RECONNECT  für PV_RECONNECT_HOLD_MS  ⇒ Victron verbinden
// Richtwerte für 12V/36-Zeller (Vmp ~18 V, Voc ~21–23 V). Bitte einmessen!
const float PV_DISCONNECT_V = 15.0;          // darunter: praktisch keine Ladeleistung → trennen
const uint32_t PV_DISCONNECT_HOLD_MS = 2000; // 2 s stabil unterhalb

const float PV_RECONNECT_V = 19.0;          // darüber: tagsüber genug Licht vorhanden → verbinden
const uint32_t PV_RECONNECT_HOLD_MS = 2000; // 2 s stabil oberhalb

// ========================= Zeiten & Pulse =========================
const uint16_t RELAY_PULSE_MS = 40;
const uint32_t PRECHARGE_MS = 2000;
const uint32_t PI_SHUTDOWN_HOLD_MS = 1500;
const uint32_t PI_SHUTDOWN_WAIT_MS = 30000; // 30 s warten

const uint32_t STABLE_REQ_MS = 3000; // für SoC-Bedingungen

const bool SERIAL_DEBUG = false; // true=Debug-Ausgaben über Serial

// ========================= Zustände =========================
enum class VictronState { Disconnected,
                          Connected };
enum class MainState { Off,
                       On };

VictronState victron = VictronState::Disconnected;
MainState mainSys = MainState::Off;

// Glättung: gleitender Mittelwert aus den letzten N Messungen
const uint8_t VOLTAGE_AVG_N = 5; // Anzahl Samples im Fenster
float bat_hist[VOLTAGE_AVG_N] = {0};
float pv_hist[VOLTAGE_AVG_N] = {0};
uint8_t vol_hist_idx = 0;   // Einfügeindex (0..VOLTAGE_AVG_N-1)
uint8_t vol_hist_count = 0; // wie viele Werte aktuell vorhanden (bis VOLTAGE_AVG_N)
// Laufende Summen für effiziente Mittelwertberechnung
float sum_bat = 0.0f;
float sum_pv = 0.0f;

// Globales Flag: Setzt setup() nach Prüfung der seriellen Schnittstelle
bool serial_active = false;
const char *reset_cause = NULL;

void delayLowPower(uint32_t ms) {
    // Zerlege ms in 8s-Blöcke + Rest
    while (ms >= 1000) {
        LowPower.powerDown(SLEEP_1S, ADC_OFF, BOD_OFF);
        ms -= 1000;
    }
    // Rest in ms
    if (ms > 0) {
        delay(ms);
    }
}

// Oversampling (einfaches Mittel)
uint16_t readAdcAveraged(uint8_t pin, uint8_t samples = 16) {
    uint32_t acc = 0;
    for (uint8_t i = 0; i < samples; i++) {
        acc += analogRead(pin);
        delayMicroseconds(200);
    }
    return (uint16_t)(acc / samples);
}
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

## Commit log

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2025-08-07 Update arduino.json to remove unnecessary output paths and set port to COM3
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2025-08-09 Enhance MJPEG stream page with mode selection and UDP control for camera operation
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2025-08-09 Add initial implementation of the weed robot system with camera, UDP communication, and robot control
2025-08-09 Enhance camera and robot control functionality with improved stream handling and command processing
2025-08-09 Enhance camera frame capture with RGB conversion and improve serial command handling with buffered reading
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2025-08-09 Refactor joystick command processing to improve motor control logic and add debug output
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2025-08-10 Refactor camera setup and heartbeat logic for improved stream handling and reliability
2025-08-10 Enhance status data collection with CPU load and frequency metrics; update HTML to display CPU temperature with color coding based on value.
2025-08-12 Add status JSON sending functionality every 5 seconds and update loop for status transmission
    [unkrautroboter.fzz]
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2025-08-13 Enhance robot control and calibration features: - Add DISTORTION mode support in robot_control.py - Implement mode persistence in state directory - Update UDP server to handle DISTORTION mode command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
2025-08-13 Refactor image capture methods to remove calibration parameter and enhance last capture handling
2025-08-13 Enhance joystick data transmission and add stream watchdog functionality; improve calibration image handling and display during calibration process
2025-08-13 Enhance calibration and camera functionality; improve snapshot capture logic and ensure camera state management
2025-08-13 Add camera check before calibration click; ignore clicks if camera is not active
2025-08-13 Update YOLO configuration and model; adjust image size and epochs, add safe execution mode, and enhance error handling for model loading
    [config.py, yolo_detector.py]
2025-08-13 feat: Add EXTRINSIK mode and related functionalities
    - Updated send_udp.php to include EXTRINSIK mode in the mode selection.
    - Modified unkrautroboter.html to add EXTRINSIK option in the mode dropdown and display relevant status messages.
    - Enhanced camera.py to allow image capture with an undistortion option, specifically for EXTRINSIK mode.
    - Adjusted robot_control.py to handle EXTRINSIK mode, including capturing images and processing extrinsics.
    - Implemented geometry.py for converting pixel coordinates to world coordinates, supporting homography and extrinsic parameters.
    - Updated status_ws_server.py to provide world transformation readiness status.
    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
2025-08-14 feat: Update CharUco board parameters for improved calibration; adjust squares and dictionary settings
2025-08-17 Refactor energy management system for solar and battery control; implement PWM for brush motor; add web server monitoring scripts
    - Updated energy management code to remove INA260 dependency and use voltage dividers for battery and PV voltage readings.
    - Implemented relay control logic for connecting/disconnecting Victron based on battery state of charge (SoC) and PV voltage.
    - Introduced PWM control for brush motor using Timer5 on Arduino Mega, improving motor speed control.
    - Added JavaScript files for monitoring web server, including heartbeat, mode change, status updates, and stream management.
    - Created configuration file for centralized IP/port settings for the web server.
2025-08-17 feat: Add reset functionality with UI button and UDP command handling
    [udp_server.py]
2025-08-17 feat: Update joypad visibility logic for manual and button-only modes; adjust send behavior for hidden pad
2025-08-17 feat: Implement status message bus for real-time updates; enhance status handling in calibration and robot control
2025-08-18 Refactor code for improved readability and consistency
    - Standardized logging format across multiple modules.
    - Reformatted code for better alignment and readability.
    - Updated comments for clarity and consistency.
    - Simplified some conditional statements and method calls.
    - Ensured consistent use of double quotes for strings.
    - Improved error handling and logging messages in serial manager.
    - Enhanced structure and organization of import statements.
    [calibration.py, camera.py, config.py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]
2025-08-18 fix: Update USE_DUMMY flag to use real YOLO model; clean up code formatting in training scripts
    [config.py]
2025-08-18 Refactor code for improved readability and consistency
    - Adjusted formatting for constant definitions and comments for better clarity.
    - Enhanced indentation and spacing in various functions to maintain uniformity.
    - Added debug print statements to provide more insight during execution.
    - Streamlined the setup process and improved the handling of serial commands.
    - Ensured consistent use of braces in control structures for better readability.
2025-08-19 refactor: Update motor control and encoder pin assignments; improve PWM initialization and analog write functions
2025-08-19 fix: Update ENCODER_BRUSH_A to polling mode and implement brush encoder polling function
    [unkrautroboter_motorsteuerung.ino]
2025-08-19 fix: Correct pin assignments for X-axis motors and update PWM initialization for brush motor
    [unkrautroboter_motorsteuerung.ino]
2025-08-19 chore: Update binary file 'unkrautroboter.fzz' with latest changes
    [unkrautroboter.fzz]
2025-09-03 fix: Update pin assignments for energy management and add LED status indicators
    [unkrautroboter.fzz]
2025-09-07 fix: Update joystick button handling and add manual control for X and Z motors
    [unkrautroboter.fzz]
2025-09-07 fix: Update joystick button handling to use compact token format (B=1) for consistency across components
    [robot_control.py, udp_server.py]
2025-09-07 fix: Update joystick command parsing to support only B= format for button input
    [udp_server.py, unkrautroboter_motorsteuerung.ino]
2025-09-07 fix: Add immediate endstop checks in MANUAL mode for responsive motor control
    [unkrautroboter_motorsteuerung.ino]
2025-09-08 fix: Add firmware upload handling in MANUAL mode and implement flashing process
    [config.py, robot_control.py]
2025-09-12 fix: Add type ignore comments for RPi.GPIO and gpiozero imports to resolve type checking issues
    [robot_control.py]
2025-09-24 fix: Adjust BAT_RTOP value based on calibration data for accurate voltage readings
    [unkrautroboter_energiemanagement.ino]
2025-10-15 fix: Update BAUDRATE comment for clarity and set FW_RESET_GPIO to 17 for proper reset functionality
    [config.py]
2025-10-28 fix: Update FW_RESET_GPIO to 23 and add SHUTDOWN_GPIO for controlled shutdown
    [unkrautroboter.fzz]
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2025-10-29 fix: Adjust shutdown timing parameters and remove unused ACK pin
    [unkrautroboter_energiemanagement.ino]
2025-10-29 feat: Implement voltage averaging for battery and PV readings to improve decision-making
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2025-11-02 feat: Implement OLED display for debugging and replace Serial output with OLED logging
    [unkrautroboter_motorsteuerung.ino]
2025-11-18 feat: Remove unused UDP status broadcast port and enhance GPIO reset logic with configurable parameters
    [config.py, robot_control.py, serial_manager.py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]
2025-11-19 Refactor motor control and display handling
    - Removed obsolete AVRlib definitions and enums related to FFT.
    - Switched from Adafruit SSD1306 to U8g2 library for OLED display management.
    - Updated PWM maximum value for motor control to 255.
    - Simplified end switch handling and added helper functions for motor PWM writing.
    - Implemented joystick input processing with ramp-up/ramp-down functionality for smoother motor control.
    - Enhanced setup and initialization routines for better OLED detection and motor configuration.
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2025-11-27 fix: Update YOLO dummy mode and adjust battery calibration parameters
    [config.py, unkrautroboter_energiemanagement.ino, unkrautroboter_motorsteuerung.ino]
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2026-09-08 feat: Enhance serial communication and error handling in SerialManager
    - Always start the read thread to ensure continuous serial communication.
    - Implement a safe port closure method and a retry mechanism for reopening the port.
    - Improve line dispatching logic for received data, including JSON status handling.
    - Introduce thread safety for command sending with a write lock.
    refactor: Update status_ws_server to use robot control abstraction
    - Simplify status retrieval by directly accessing the robot instance.
    - Ensure joystick status is fetched from the correct robot instance.
    chore: Clean up imports in training and udp_server modules
    - Remove unnecessary imports to streamline the codeb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
    [camera.py, robot_control.py, serial_manager.py]
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2026-09-09 feat: labeling/training pipeline phases 3-4 (export, train_now, trainer UI)
    Phase 3 (complete)
    - trainer/common.py: studio_stopped() context manager — flock-serialised
    stop/db-work/close/start dance, so the 5-min reindex timer can't collide
    with manual export/train runs. db_manager.close() before restart (else the
    service crash-loops on the DuckDB lock). REST list_images() paginates
    (server caps limit at 100).
    - trainer/export_confirmed.py: export tagged samples to a canonical YOLO
    dir; remap class ids from LightlyStudio's alphabetical order to
    common.CLASSES = [unkraut, moos]; reviewed-but-empty -> negative .txt.
    Reusable export_tag(tag, out, exclude_tags).
    - trainer/lightly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
2026-09-09 fix(trainer): absolute data.yaml path, --no-gate, env-configurable
    Found while smoke-testing the full loop with 40 dummy frames derived from
    the one real capture (ingest -> preannotate 235 boxes -> tag reviewed ->
    make_holdout -> train_now -> promote -> NCNN/ONNX export -> pi_inbox_staging,
    all verified):
    - export_confirmed.py: write `path: <abs>` in data.yaml — ultralytics
    val()/train() resolve `path: .` against the wrong cwd and can't find the
    images.
    - train_now.py: add --no-gate (promote despite the holdout regression check;
    metrics still record the reasons) for exactly this kind of test.
    - common.py: STUDIO_UNIT and LS_DATASET are now env-overridable.
    Known cosmetic gaps for l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
2026-09-09 feat: phase 5 — model OTA to the Pi (bin/deploy-model.sh + robot_control)
    Mirrors the .hex firmware OTA. Verified end-to-end against the live Pi
    (v8m model, runtime=pt): valid tar -> validate -> atomic swap -> hot
    reload -> .uploaded; wrong classes -> .failed, model untouched.
    - bin/deploy-model.sh: pull best.pt/best.onnx/best_ncnn_model/ + metrics.json
    from .17 (or --from DIR), drop __pycache__, build model_<ts>.tar with a
    manifest.json (sha256 per file, classes, imgsz), scp to the Pi. scp to a
    .part name + atomic mv so the Pi's 0.1 s scan never sees a half file.
    --dry-run / --force / --imgsz / --classes.
    - src/config.py: MODEL_UPLOAD_DIR, MODEL_DIR, YOLO_NCNN_DIR, YOLO_RUNTIME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
    [config.py, robot_control.py, yolo_detector.py]
2026-09-09 feat: phase 6 — Pi env on ultralytics 8.4 + NCNN, ARM64 probe
    The plan's #1 risk is cleared: NCNN inference works on the Pi 4B (ARM64).
    The 8.4.0 NotImplementedError (#23281) is fixed in ultralytics 8.4.146.
    Probe on the real Pi (throwaway overlay, prod env untouched):
    v8m .pt @640 13.3 s (baseline on 8.4)
    YOLO26s NCNN @1280 ~4.5 s <- target resolution, well under the 20 s budget
    YOLO26s NCNN @960 2.4 s
    YOLO26s ONNX @640 31 s (fallback not needed)
    -> runtime decision: ncnn @ imgsz 1280. No ncnn_direct, no ONNX.
    - pyvenv bumped in place to ultralytics 8.4.146 + ncnn (torch stays
    2.8.0+cpu); roboter.service restarts cleanly, v8m still loads/predicts.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
    [config.py]
2026-09-09 feat: "Trainieren & deployen" button in the .4 dashboard
    One click on the operator UI -> train on .17 -> on a passing gate, ship
    best.pt to the Pi's model OTA. Chain verified end-to-end (auth, status
    proxy, deploy step); a full train run is left for real data.
    .17
    - yolo-training/box/deploy-to-pi.sh: build model_<ts>.tar from
    pi_inbox_staging (manifest + sha256, drop __pycache__), scp .part + mv to
    admin@pi:/home/admin/model_upload/. Uses the pull key. Refuses a non-pass
    gate. bin/deploy-model.sh stays as the manual dev-PC path.
    - trainer/serve.py: reworked into a train+deploy control server —
    POST /train (token, deploy=1 chains deploy-to-pi.sh after a passing
    gate), POST /deplo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
2026-09-09 chore: set the shared LAN control token (was the change-me placeholder)
    Same value in all four places now — send_udp.php, js/config.js, train.php
    (all on .4), and .17:~/lightly/trainer.env. Verified end-to-end: the new
    token drives /train, /deploy and RESET; the old placeholder is rejected 403.
    It is a LAN nuisance-guard, not a secret (it ships in js/config.js) — this
    matches the existing design.
    Claude-Session: https://claude.ai/code/session_01XWNhnYoXB5TE7GiEXojjDv
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2026-09-10 EXTRINSIK: Messpositionen weg vom Board-Rand (Feldtest zeigte Massstab 1.11)
    Erster Lauf am Roboter: Residuum 5.5 mm ok, aber Massstab 1.114. Rohdaten:
    board_x liest bei mech_x 150/290/440 -> 150.0 / 285.7 / 410.0, also
    zunehmende Kompression zum fernen Board-Rand (500 mm). Ursache: am Rand
    fehlen einseitig die Ecken, der Schwerpunkt des verdeckten Nests wird nach
    innen gezogen. In der Board-Mitte ist die Messung exakt (mech 150 -> 150.0).
    Fix vorerst: targets_mm (0, 150, 290, 440) -> (0, 120, 250, 380); alle
    Messpositionen >= 120 mm vom fernen Rand. Der robuste Fix bleibt der
    ArUco-Marker an der Buerste (kein Verdeckungs-Proxy).
    Clau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
    [calibration.py]
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2026-09-11 Dashboard: last_capture als PNG, CSS vereinheitlicht, Layout-/Font-Fixes
    - last_capture.png statt last_capture.jpg: zeigt jetzt das AUTO-
    Erkennungsbild verlustfrei in Originalaufloesung (das Bild, das YOLO
    tatsaechlich auswertet) statt eines herunterskalierten JPEGs.
    - style.css: wiederholte Box-/Button-Styles (Status/Arduino/Letzte
    Aufnahme/Reset/Training) zu .panel/.wide/.panel-title zusammengefasst
    statt pro ID dupliziert. Die einzigen zwei hart codierten Inline-Styles
    (CPU-Temp-Warnfarbe, blaue EXTRINSIK/DISTORTION-Statusmeldung) waren aus
    status.js per JS-String erzeugt - jetzt als Klassen (.temp-warn/.temp-hot/
    .status-message), JS setzt nur noch den Klassennamen.
    - #mod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
